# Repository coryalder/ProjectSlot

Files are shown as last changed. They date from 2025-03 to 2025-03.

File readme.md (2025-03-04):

# Project Slot

A 3d printable mounting system for small modular projects. Inspired by DIN-rails, and compatible with 2020 aluminum extrusion.

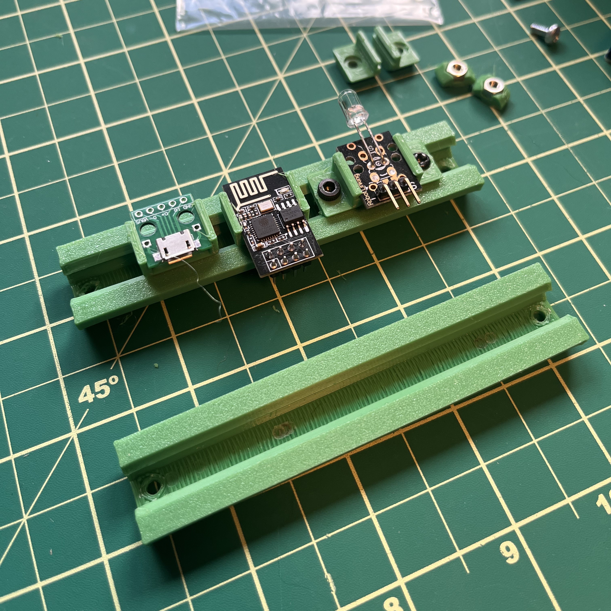
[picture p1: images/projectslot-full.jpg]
photo of a full projectslot rail


# Components

- `projectslot`: stls/projectslot-v2-100mm.stl
    - These are the mounting rails. They are modelled on the v-slot in 2020 aluminum extrusion, and lots of hardware that works with 2020 should work with them. They have M3 holes at both ends to make them easy to mount. The rails are 100mm long, but could be extended to any length your 3d printer can handle.
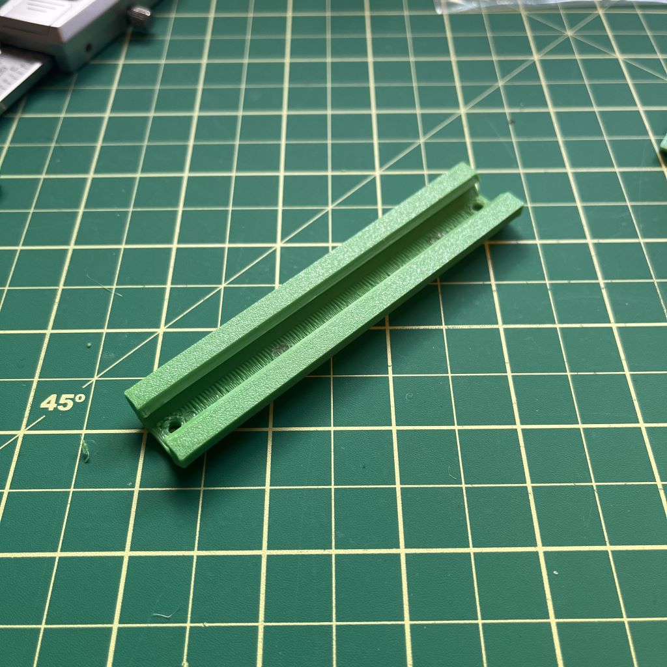
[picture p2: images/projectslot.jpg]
photo of projectslot
    - 
- `pcb-mounts`: stls/ps-pcb-mount-v3.stl
    - This is a little PCB side clip that clamps on using a t-nut and an M3x6 bolt. Use two to mount a PCB. This component is more flexible since you don't need to know the PCB size ahead of time, but it can be hard to clamp the PCB on tightly, and requires the most hardware. 3d printable t-nuts can be found on thingiverse [here](https://www.thingiverse.com/thing:3050607) & [here](https://www.thingiverse.com/thing:1609323).
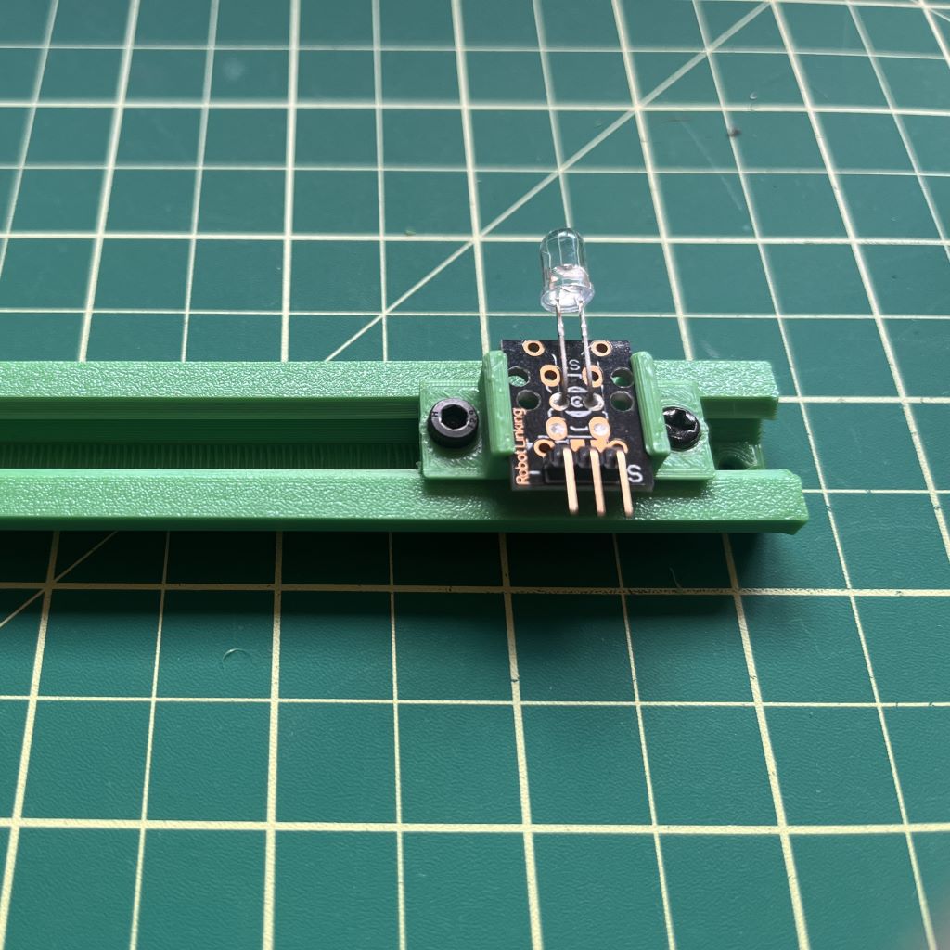
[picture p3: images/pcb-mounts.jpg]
photo of pcb-mounts
    - 
- `pcb-slide-in-clip`: stls/ps-*mm-pcb-slide-in-clip.stl
    - This is a friction fit component for holding a small PCB in place. It uses no hardware, but you'll have to generate a model that's exactly the width of your PCB to use this. It's also a bit sensitive to the calibration of your printer - so you may have to play with the "PCB width" variable a bit to get a tight (but not too tight) fit.
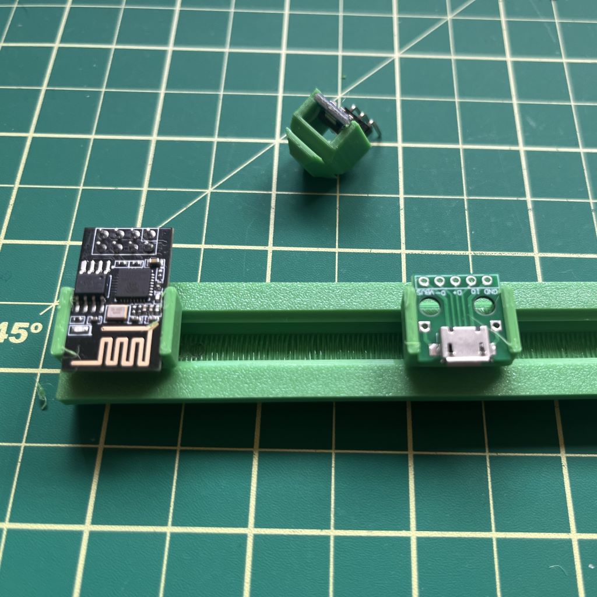
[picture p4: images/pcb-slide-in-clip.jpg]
photo of pcb-slide-in-clip
    - 

# CAD

The project is built in FreeCAD, which I am VERY new to so if you have suggestions for ways to improve the CAD, please make a PR or open an issue. Editable parameters are found in a FreeCAD spreadsheet, for quick editing.

Note: if you make `Spreadsheet.pcb_width` too small when adjusting `pcb-slide-in-clip`, you'll have to reduce `Spreadsheet.chamfer` as well. When shrinking the PCB width, if you notice one of the sides getting cut off, try changing in 1mm increments - freecad seems to get confused if you change it too dramatically.

# Printing tips

- All the accessories print without supports. 0.2mm layer height works well. Print in the same orientation as they sit on the rail - all the angles are 45 degrees so you shouldn't need supports to print them.
- The rails print best with the open side down. I used tree supports for around the two mounting holes.

# generate.py script

If you have freecad installed in an expected place, you should be able to use this script to generate models parametrically:

```
usage: generate.py [-h] [--length LENGTH] action

Generate STLs dynamically from a FreeCAD file

positional arguments:
  action           the stl to generate: all | rail | pcb-mount | pcb-clip

options:
  -h, --help       show this help message and exit
  --length LENGTH  the length of the rail or width of pcb-clip, does nothing with pcb-holder
```

Examples:

1. `python3 generate.py all` - generate all models, with default parameters
2. `python3 generate.py rail --length 200` generate a 200mm rail in `stls/projectslot.stl`
3. `python3 generate.py pcb-clip --length 22` generate a 22mm pcb clip in `stls/pcb-slide-in-clip.stl`
4. `python3 generate.py pcb-mount` generate the pcb mount in `stls/ps-pcb-mount.stl`

# Todos

- More mounting styles
- Auto generate stls in a bunch of common sizes using github actions
- Find a way to print rails without supports

# Useful compatible models

I haven't tested these all, but they should work;

- t-nuts [thing:3050607](https://www.thingiverse.com/thing:3050607) & [thing:1609323](https://www.thingiverse.com/thing:1609323).
- [snap in PCB mount (use with t-nuts)](https://www.printables.com/model/304699-configurable-snap-in-pcb-mount).
- [Twist-in cable clamp](https://www.thingiverse.com/thing:2613532).
- [2020 flat cable clip](https://www.thingiverse.com/thing:2367717).
- [cable clip for 2020 profile voron](https://www.thingiverse.com/thing:5204184).

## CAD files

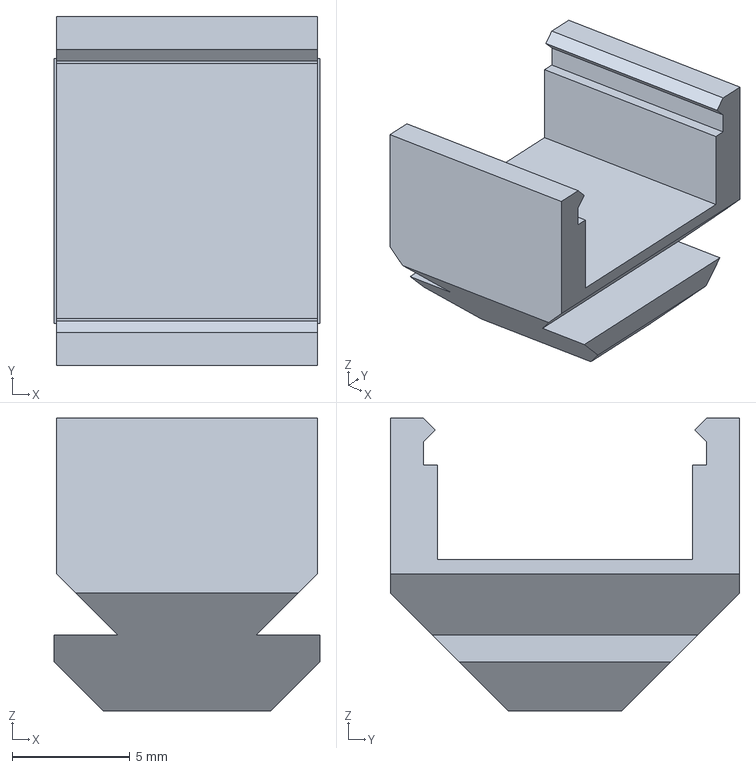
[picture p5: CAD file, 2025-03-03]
projectslot.FCStd
11.3 x 14.8 x 12.4 mm

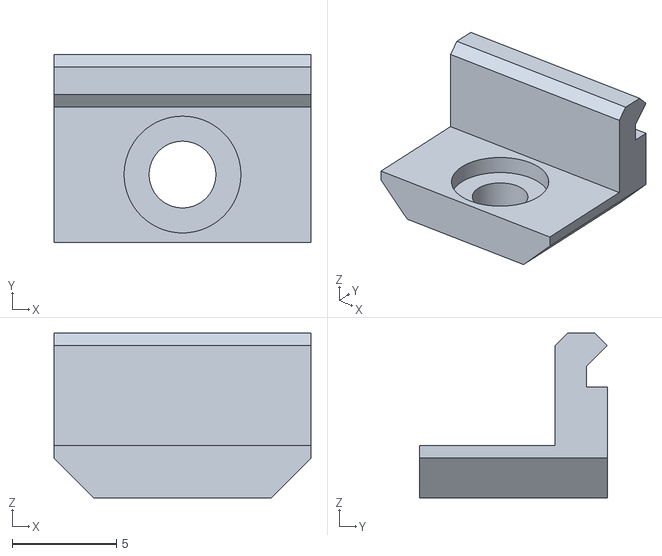
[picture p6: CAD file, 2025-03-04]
stls/ps-pcb-mount.stl
12.3 x 9.00 x 7.92

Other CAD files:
stls/pcb-slide-in-clip.stl
stls/projectslot.stl

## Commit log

2025-03-02 move stls into build dir
    [projectslot-v2.stl, ps-14.25mm-pcb-slide-in-clip.stl, ps-14.75mm-pcb-slide-in-clip.stl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]
2025-03-02 add readme, add parameters to cad
    [projectslot-v2-100mm.stl, projectslot.FCStd, ps-pcb-mount-v3.stl]
2025-03-02 add printing tips, todos, and links to models
2025-03-03 switch to upload artifacts v4
2025-03-03 switch to stable, don't use freecadcmd
2025-03-03 switch to varset from spreadsheet
    [projectslot.FCStd]
2025-03-03 switch to using the appimage
2025-03-04 fix stl path
2025-03-04 update stls, remove unused, add generate script to readme
    [pcb-slide-in-clip.stl, projectslot-v2-100mm.stl, projectslot.stl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]
